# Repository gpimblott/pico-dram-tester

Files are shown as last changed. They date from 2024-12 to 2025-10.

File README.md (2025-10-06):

# Pico DRAM Tester

Having trouble with your old-school DIP dynamic RAM chips? Here's a simple
RAM tester that will give you a definitive pass or fail for a variety of
chips.

**This is an updated version with additional tests and refaftoring of the code.
Based on the early beta release by schlae . The software is not completed. Feel free to
build a tester and try it out, and submit bug reports.**

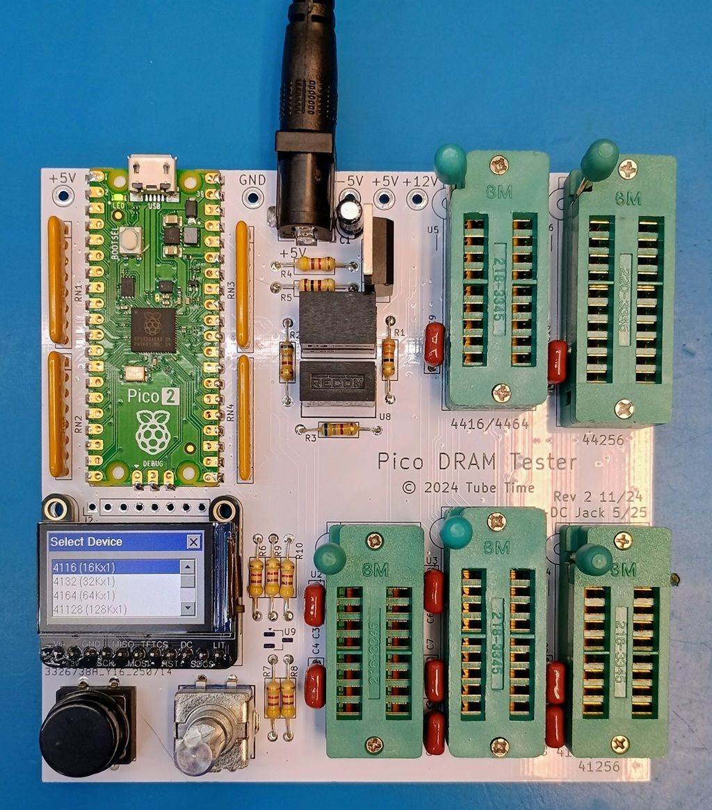
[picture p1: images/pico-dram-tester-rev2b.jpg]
Photo of the board


Benefits

* Tests RAM *at full speed* so you can feel confident about a chip that passes.
* Easy to construct with widely-available parts. No surface mount chips.
* Low cost
* Built-in DC-DC modules generate extra voltages required by 4116-class chips
* Can be operated from a bench supply for voltage margin testing

Supported Devices

* 4027 (4K x 1)
* 4108 (8K x 1 that are 4116s with only half test good: MK4108, TMS4108, etc)
* 4116 (16K x 1)
* 4132 (32K x 1, piggyback)
* 4132 (32K x 1 that are 4164s with only half tested good: TMS4532, M3732)
* 4164 (64K x 1)
* 41128 (128K x 1, piggyback)
* 41256 (256K x 1)
* 4416 (16K x 4)
* 4464 (64K x 4)
* 44256 (256K x 4)

Out of scope

* SRAM, DRAM chips larger than 1MBit
* Logic chips

## Versions
* 0.1 - Beta version designed and coded by schlae (@tubetime)
* 0.2 - Changed to higher voltage as recommended by schlae in notes below.
* 0.3 - Restructure code by G.Pimblott and merged in board changes for DC Jack by Markeno76
* 0.4 - Added Checkerboard test
* 0.5 - Added Address error test

## Construction

Revision 2.2 adds a DC Barrel Jack option.  
It also adds solder jumper pads to allow use of the original Panasonic Encoder
or the common Generic Encoders.

[Fab package](fab/pico-dram-tester-rev2.zip)

[Schematic](pico-dram-tester.pdf)

[Bill of Materials](pico-dram-tester.csv)

The board is a simple 2-layer board, 100mm x 100mm, and 1.6mm thick. Fabricate
at your favorite vendor in any color you wish.

You may populate the board only with the sockets for devices you plan to use,
or you may populate all the sockets. You can try substituting the sockets with
standard IC sockets, but I recommend ZIF sockets which are much easier to use.
Why so many sockets? It saves you from having to install dozens of pin control
transistors required to make a tester work with a single universal socket.

Populate Q1, U7, U8, R2, R3, R4, and R5 if you would like to test 4116 and
4132 devices without requiring an external -5V and +12V power supply.

If you want to provide the -5V, +5V, and +12V power from your bench supply,
then you may leave those components off of the board and connect your power
leads to the -5V, +5V, and +12V test points. If you don't plan to test 4116
or 4132 chips, then you can safely leave out those components.

The LCD display is nominally the [Adafruit 4383](https://www.adafruit.com/product/4383) which is to be installed at location J1 (U9 is not required when using
this display). You can also use cheaper devices available from Aliexpress and
others. They are 8-pin LCD displays sold as 1.14" 135x240 IPS ST7789 modules.
Install this display at position J2. You may also need to add the voltage
monitor at position U9.

For several reasons, this board requires a Pico 2 microcontroller board and
will not work at all with the Pico 1.

After installing all the components and inspecting the board for accidental
short circuits, connect the Pico 2 via the USB connector to a computer. The
device should power up and appear as a USB mass storage device. Copy the
prebuilt firmware file [pmemtest.uf2](firmware/pmemtest.uf2) to this device, and the Pico 2 will
program itself. Reset the power and you should see a menu of chips on the LCD
screen.

## Using the DRAM Tester

Before starting, connect the tester to a power source:

* If you did not install U7 and U8, connect a bench supply to the GND, -5V, +5V, and +12V test points. Connect the Pico 2 USB jack to a power adapter or computer.
* If you installed U7 and U8, connect a 5V bench supply to the 5VIN and GND test points. Instead of a bench supply, you could connect the Pico 2 USB jack to a power adapter, but you won't be able to control the voltage. A computer often has a much lower voltage and you may fail RAM chips that actually function at 5V.

1. Install the chip in the socket designated for that type of memory chip, following the pin 1 orientation (the pin 1 notch faces the ZIF socket lever). Note that some of the sockets are used for several types of memory.
2. Rotate the selection knob until the correct part number is highlighted, and push down on the top of the selection knob (it's also a button!)
3. If you make a mistake, press the button to the left of the selection knob to go back.
4. After selecting a part, you need to pick the correct speed grade to run the
test. Often the speed grade is marked on the chip as a suffix. For example, -15
typically means 150ns. If you're not sure, pick the slowest speed.
5. If you are using an external bench power supply to supply -5V and +12V, turn it on now. If you soldered in the on-board voltage converter modules, you don't need to do anything. Push the top of the selection knob to continue.
6. The test runs. You will see a red "X" if the test fails or a green checkmark if the test passes.
7. You can rerun the test immediately by pushing down on the top of the selection knob. Or go back to the menu by pushing the button to the left.

Note: The visualization pane on the left is just for entertainment and doesn't
really represent bad bits.

## Technical Details

The Pico 2 microcontroller (RP2350) has built-in high-speed PIO processors
which are overclocked to 300MHz. This means that the DRAM timing can be set
to a resolution of 3.3ns. The RAM test runs on the second CPU core, decoupling
it from the GUI, which runs on the first CPU core.

RAM testing can be surprisingly complicated. There are many kinds of failures:

* Stuck-at fault - a cell is stuck at a 1 or a 0
* Stuck-open fault - a cell isn't connected (input or output)
* Transition fault - a cell can't go from one state to another (1 to 0 or 0 to 1)
* Data retention fault - a cell flips after a time delay
* Coupling fault - the state of one cell affects the state of another
* Neighborhood pattern sensitive fault - a specific pattern in nearby cells causes a cell to flip
* Address decoder fault - cells may be isolated, or multiple cells accessed at the same address, or multiple addresses may access a single cell

There are a number of "traditional" RAM tests such as the checkerboard or
walking 1/0, but these tests can be slow and don't have precise coverage over
all failure modes. The Pico DRAM Tester uses more modern testing algorithms:

* March-B. This is a sequence of linear reads and writes designed to catch address faults, stuck-at faults, transition faults, and coupling faults.
* Pseudorandom test. This test loads a pseudorandom number sequence into the memory, reads it back, and checks to make sure it didn't change. The test is repeated with 64 different pseudorandom patterns to enhance coverage. The patterns are identical between runs, making the test repeatable. The test only uses pseudorandom data and does not randomize the address. This test can detect many pattern-sensitive faults.
* Refresh test. This test loads a pattern into the memory, waits for a time delay, and then tries to read it back. The time delay is longer than a typical refresh rate. This test can detect data retention faults.

## Known Issues

* The 41128 test is not yet reliable.

## Troubleshooting

Check your solder connections. Does the Pico 2 board show up in bootloader mode when you plug it into a computer?

The Pico DRAM Tester uses an overclocked Pico 2 configuration.
Some Pico 2 boards may not work well at 300MHz, crashing or not drawing the GUI on the screen correctly.
You may be able to get it working by editing pmemtest.c, find the line `vreg_set_voltage(VREG_VOLTAGE_1_15);` and change the voltage setting to `VREG_VOLTAGE_1_20`.

## License

This work is licensed under a Creative Commons Attribution-ShareAlike 4.0
International License. See [https://creativecommons.org/licenses/by-sa/4.0/](https://creativecommons.org/licenses/by-sa/4.0/).

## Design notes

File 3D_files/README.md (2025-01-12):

# Rotary encoder knob

For those who want one, rotary_encoder_8mm.stl is a STL file of a knob for the rotary encoder made with the help of this script:

 Trimmer/Potentiometer/Rotary encoder knob (customizable) by wanderlustig on Thingiverse: https://www.thingiverse.com/thing:6752822

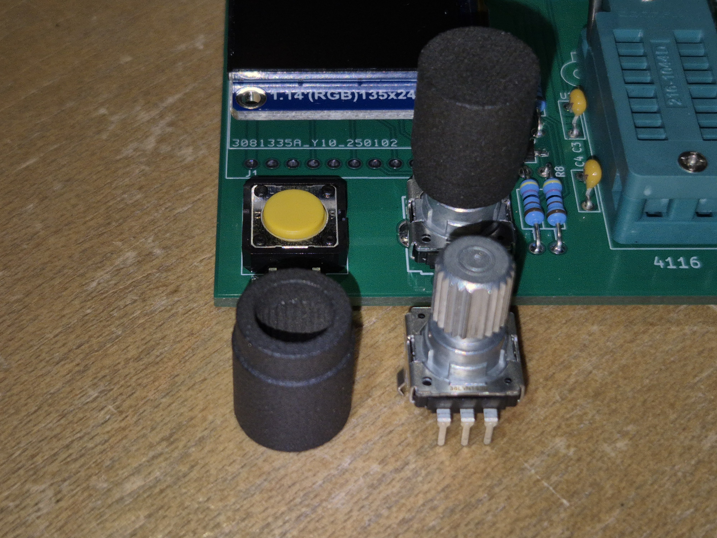
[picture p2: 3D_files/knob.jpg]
Photo of the printed knob


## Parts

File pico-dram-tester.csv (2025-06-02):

Qty | Reference | Value | DNP | Mouser
1 | C1 | 10uF |  | 667-ECA-1VM100
9 | C2,C3,C4,C5,C6,C7,C8,C9,C10 | 0.1uF |  | 80-C322C104M5U
1 | J1 | TFT 4383
1 | J2 | mrd_114_ips_lcd_8p
1 | Q1 | SUP53P06-20-E3 or equiv |  | 781-SUP53P06-20-E3
1 | R1 | 33 |  | 594-MBB02070C3309FCT
2 | R2,R3 | 680 |  | 594-MBB02070C6800FCT
6 | R4,R6,R7,R8,R9,R10 | 4.7K |  | 594-MBB02070C4701FCT
1 | R5 | 100 |  | 594-MBB02070C1000FCT
4 | RN1,RN2,RN3,RN4 | 33 |  | 652-4608X-2LF-33
1 | SW1 | RotaryEncoder_Switch |  | 667-EVE-YBCAJO16B
1 | SW2 | BACK |  | 653-B3F-4005
1 | TP1 | 5V |  | 534-5005
2 | TP2,TP6 | GND |  | 534-5006
1 | TP3 | 12V |  | 534-5009
1 | TP4 | -5V |  | 534-5007
1 | TP5 | 5VIN |  | 534-5005
1 | U1 | PICO2 |  | 358-SC1631
1 | U2 | 4116
1 | U3 | 4132
1 | U4 | 4164/41128/41256
1 | U5 | 4416/4464
1 | U6 | 44256
1 | U7 | DCDC_ITR03 |  | 490-ITR0305S12
1 | U8 | RFM-0505S |  | 919-RFM-0505S
1 | U9 | APX803S |  | 621-APX803S-29SA-7

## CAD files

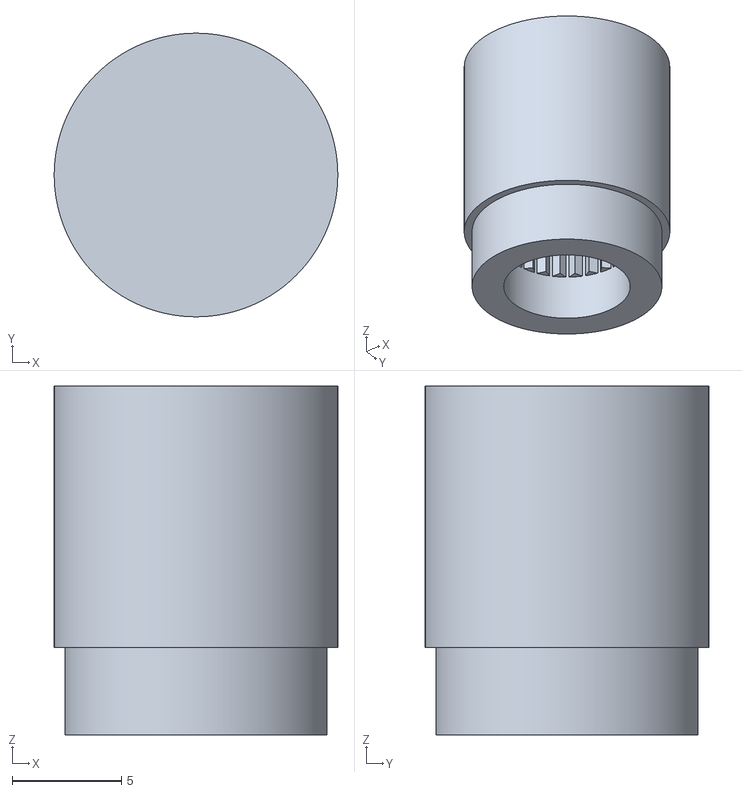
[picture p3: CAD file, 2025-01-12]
3D_files/rotary_encoder_8mm.stl
13.0 x 13.0 x 16.0

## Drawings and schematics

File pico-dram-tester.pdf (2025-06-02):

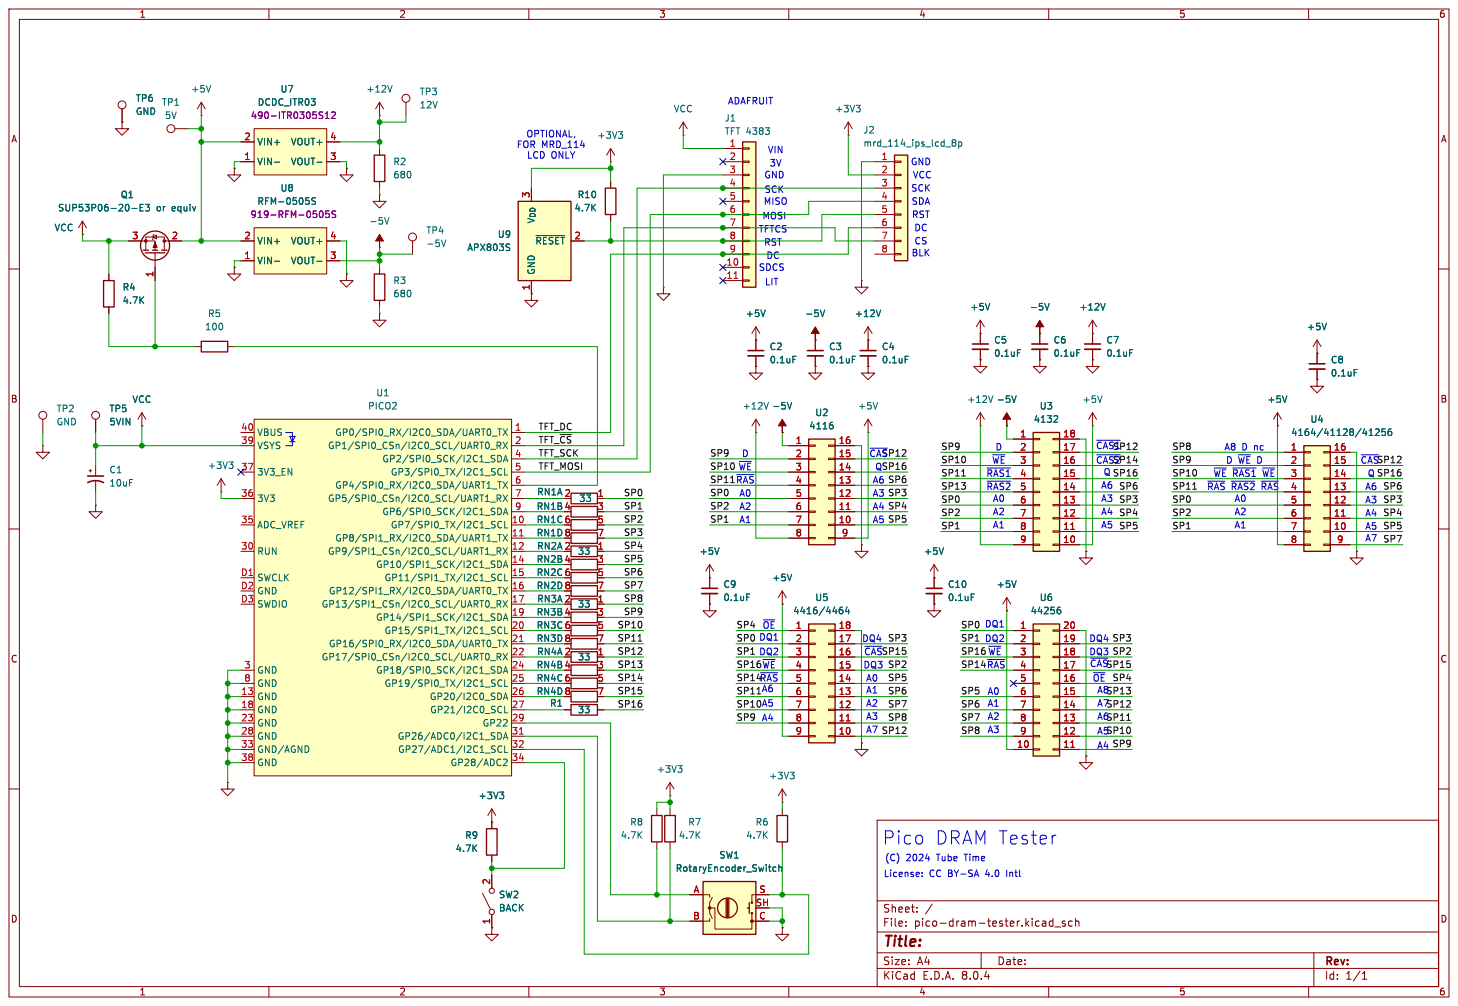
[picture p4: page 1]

License: CC BY-SA 4.0 Intl (C) 2024 Tube Time Pico DRAM Tester

Id: 1/1 Title: File: pico-dram-tester.kicad_sch Sheet: /

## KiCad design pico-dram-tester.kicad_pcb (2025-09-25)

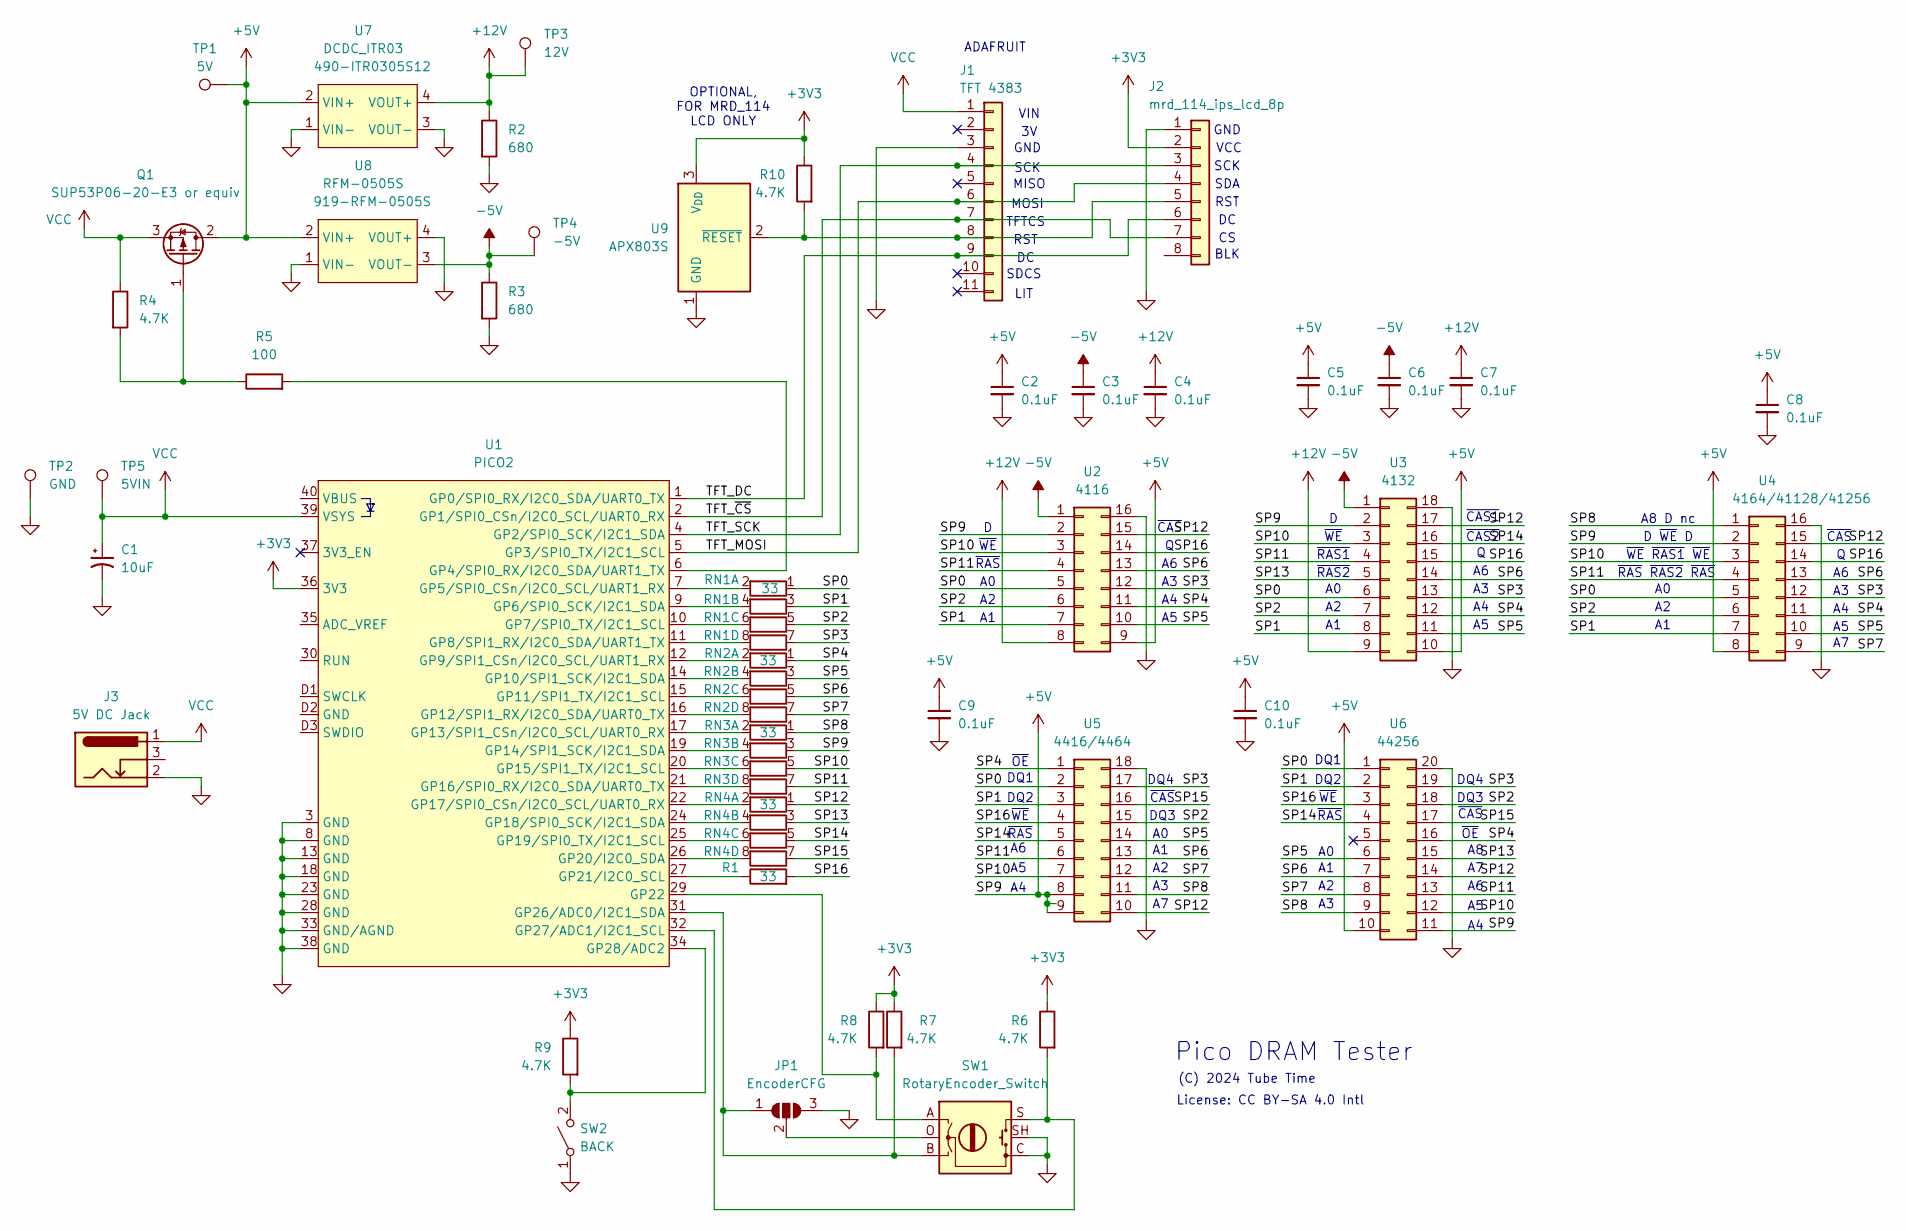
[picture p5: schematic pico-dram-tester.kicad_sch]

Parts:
C1: 10uF; CAPAE200P500X1100; Mouser 667-ECA-1VM100
C2, C3, C4, C5, C6, C7, C8, C9, C10: 0.1uF; CAPAC200; Mouser 80-C322C104M5U
J1: TFT 4383; ADAFRUIT_4383
J2: mrd_114_ips_lcd_8p; PinHeader_1x08_P2.54mm_Vertical
J3: 5V DC Jack; BarrelJack_Horizontal
JP1: EncoderCFG; SolderJumper-3_P1.3mm_Open_Pad1.0x1.5mm
Q1: SUP53P06-20-E3 or equiv; TO-220-3_Vertical; Mouser 781-SUP53P06-20-E3
R1: 33; RESA500; Mouser 594-MBB02070C3309FCT
R2, R3: 680; RESA500; Mouser 594-MBB02070C6800FCT
R4, R6, R7, R8, R9, R10: 4.7K; RESA500; Mouser 594-MBB02070C4701FCT
R5: 100; RESA500; Mouser 594-MBB02070C1000FCT
RN1, RN2, RN3, RN4: 33; R_Array_SIP8; Mouser 652-4608X-2LF-33
SW1: RotaryEncoder_Switch; PANASONIC_EVEY; Mouser 667-EVE-YBCAJO16B
SW2: BACK; SW_SPST_Omron_B3F-50xx; Mouser 653-B3F-4005
TP1: 5V; TestPoint_Keystone_5005-5009_Compact; Mouser 534-5005
TP2: GND; TestPoint_Keystone_5005-5009_Compact; Mouser 534-5006
TP3: 12V; TestPoint_Keystone_5005-5009_Compact; Mouser 534-5009
TP4: -5V; TestPoint_Keystone_5005-5009_Compact; Mouser 534-5007
TP5: 5VIN; TestPoint_Keystone_5005-5009_Compact; Mouser 534-5005
U1: PICO2; Pico2; Mouser 358-SC1631
U2: 4116; DIP_Socket-16_W4.3_W5.08_W7.62_W10.16_W10.9_3M_216-3340-00-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
U3: 4132; DIP_Socket-18_W4.3_W5.08_W7.62_W10.16_W10.9_3M_218-3341-00-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
U4: 4164/41128/41256; DIP_Socket-16_W4.3_W5.08_W7.62_W10.16_W10.9_3M_216-3340-00-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
U5: 4416/4464; DIP_Socket-18_W4.3_W5.08_W7.62_W10.16_W10.9_3M_218-3341-00-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
U6: 44256; DIP_Socket-20_W4.3_W5.08_W7.62_W10.16_W10.9_3M_220-3342-00-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
U7: DCDC_ITR03; Mouser 490-ITR0305S12
U8: RFM-0505S; DCDC_ITR03; Mouser 919-RFM-0505S
U9: APX803S; SOT-23_Handsoldering; Mouser 621-APX803S-29SA-7

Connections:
+3V3: J2.2, R6.1, R7.1, R8.1, R9.1, R10.1, U1.36 (3V3), U9.3 (V_{DD})
+5V: C2.1, C5.1, C8.1, C9.1, C10.1, Q1.2 (D), RN3.3 (R2.1), TP1.1, U2.2, U2.9, U3.2, U3.10, U4.2, U4.8, U5.8, U5.9, U6.10, U6.11, U7.2 (VIN+), U8.2 (VIN+)
+12V: C4.1, C7.1, R2.1, TP3.1, U2.8, U3.9, U7.4 (VOUT+)
-5V: C3.1, C6.1, R3.1, TP4.1, U2.1, U3.1, U8.3 (VOUT-)
/SP0: RN1.1 (R1.1), U2.5, U3.6, U4.5, U5.2, U6.1
/SP1: RN1.3 (R2.1), U2.7, U3.8, U4.7, U5.3, U6.2
/SP2: RN1.5 (R3.1), U2.6, U3.7, U4.6, U5.15, U6.18
/SP3: RN1.7 (R4.1), U2.12, U3.13, U4.12, U5.17, U6.19
/SP4: RN2.1 (R1.1), U2.11, U3.12, U4.11, U5.1, U6.16
/SP5: RN2.3 (R2.1), U2.10, U3.11, U4.10, U5.14, U6.6
/SP6: RN2.5 (R3.1), U2.13, U3.14, U4.13, U5.13, U6.7
/SP7: RN2.7 (R4.1), U4.9, U5.12, U6.8
/SP8: RN3.1 (R1.1), U4.1, U5.11, U6.9
/SP10: RN3.5 (R3.1), U2.3, U3.3, U4.3, U5.7, U6.12
/SP11: RN3.7 (R4.1), U2.4, U3.4, U4.4, U5.6, U6.13
/SP12: RN4.1 (R1.1), U2.15, U3.17, U4.15, U5.10, U6.14
/SP13: RN4.3 (R2.1), U3.5, U6.15
/SP14: RN4.5 (R3.1), U3.16, U5.5, U6.4
/SP15: RN4.7 (R4.1), U5.16, U6.17
/SP16: R1.2, U2.14, U3.15, U4.14, U5.4, U6.3
/TFT_DC: J1.9, J2.6, U1.1 (GP0/SPI0_RX/I2C0_SDA/UART0_TX)
/TFT_MOSI: J1.6, J2.4, U1.5 (GP3/SPI0_TX/I2C1_SCL)
/TFT_SCK: J1.4, J2.3, U1.4 (GP2/SPI0_SCK/I2C1_SDA)
/TFT_~CS: J1.7, J2.7, U1.2 (GP1/SPI0_CSn/I2C0_SCL/UART0_RX)
GND: C1.2, C2.2, C3.2, C4.2, C5.2, C6.2, C7.2, C8.2, C9.2, C10.2, J1.3, J2.1, J3.2, JP1.3 (B), R2.2, R3.2, SW1.C, SW1.SH, SW2.1 (A), TP2.1, U1.3 (GND), U1.8 (GND), U1.13 (GND), U1.18 (GND), U1.23 (GND), U1.28 (GND), U1.33 (GND/AGND), U1.38 (GND), U2.16, U3.18, U4.16, U5.18, U6.20, U7.1 (VIN-), U7.3 (VOUT-), U8.1 (VIN-), U8.4 (VOUT+), U9.1 (GND)
unnamed: J1.8, J2.5, R10.2, U9.2 (~RESET)
unnamed: JP1.1 (A), R7.2, SW1.B, U1.31 (GP26/ADC0/I2C1_SDA)
unnamed: JP1.2 (C), SW1.O
unnamed: Q1.1 (G), R4.2, R5.1
unnamed: RN1.2 (R1.2), U1.7 (GP5/SPI0_CSn/I2C0_SCL/UART1_RX)
unnamed: RN1.4 (R2.2), U1.9 (GP6/SPI0_SCK/I2C1_SDA)
unnamed: RN1.6 (R3.2), U1.10 (GP7/SPI0_TX/I2C1_SCL)
unnamed: RN1.8 (R4.2), U1.11 (GP8/SPI1_RX/I2C0_SDA/UART1_TX)
unnamed: RN2.2 (R1.2), U1.12 (GP9/SPI1_CSn/I2C0_SCL/UART1_RX)
unnamed: RN2.4 (R2.2), U1.14 (GP10/SPI1_SCK/I2C1_SDA)
unnamed: RN2.6 (R3.2), U1.15 (GP11/SPI1_TX/I2C1_SCL)
unnamed: RN2.8 (R4.2), U1.16 (GP12/SPI1_RX/I2C0_SDA/UART0_TX)
unnamed: RN3.2 (R1.2), U1.17 (GP13/SPI1_CSn/I2C0_SCL/UART0_RX)
unnamed: RN3.4 (R2.2), U1.19 (GP14/SPI1_SCK/I2C1_SDA)
unnamed: RN3.6 (R3.2), U1.20 (GP15/SPI1_TX/I2C1_SCL)
unnamed: RN3.8 (R4.2), U1.21 (GP16/SPI0_RX/I2C0_SDA/UART0_TX)
unnamed: RN4.2 (R1.2), U1.22 (GP17/SPI0_CSn/I2C0_SCL/UART0_RX)
unnamed: RN4.4 (R2.2), U1.24 (GP18/SPI0_SCK/I2C1_SDA)
unnamed: RN4.6 (R3.2), U1.25 (GP19/SPI0_TX/I2C1_SCL)
unnamed: RN4.8 (R4.2), U1.26 (GP20/I2C0_SDA)
unnamed: R9.2, SW2.2 (B), U1.34 (GP28/ADC2)
unnamed: R5.2, U1.6 (GP4/SPI0_RX/I2C0_SDA/UART1_TX)
unnamed: R1.1, U1.27 (GP21/I2C0_SCL)
unnamed: R8.2, SW1.A, U1.29 (GP22)
unnamed: R6.2, SW1.S, U1.32 (GP27/ADC1/I2C1_SCL)
VCC: C1.1, J1.1, J3.1, Q1.3 (S), R4.1, TP5.1, U1.39 (VSYS)

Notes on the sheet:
~{OE}
~{CAS}
~{RAS}
ADAFRUIT
GND
BLK
LIT
~{WE}
~{CAS2}
~{CAS1}
License: CC BY-SA 4.0 Intl
MOSI
DQ2
SDCS
(C) 2024 Tube Time
DQ3
~{RAS} ~{RAS2} ~{RAS}
OPTIONAL, FOR MRD_114 LCD ONLY
A8 D nc
DQ1
TFTCS
DQ4
SCK
~{RAS1}
~{RAS2}
VIN
SDA
VCC
Pico DRAM Tester
D ~{WE} D
~{WE} ~{RAS1} ~{WE}
RST
MISO

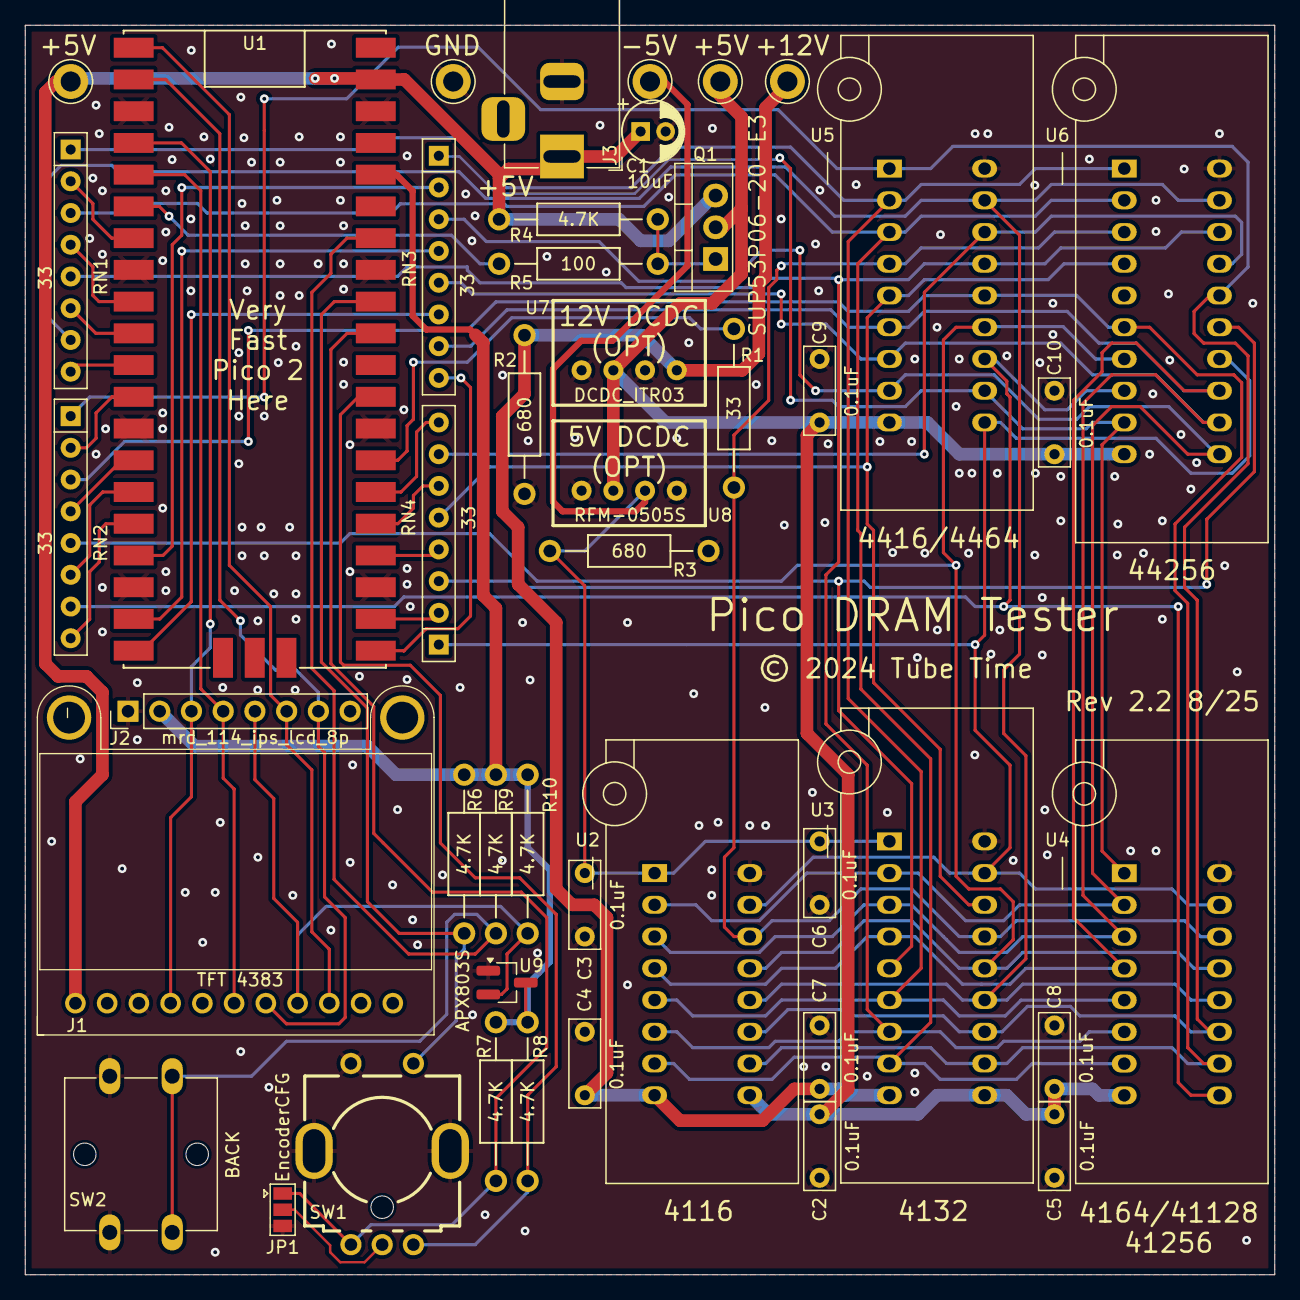
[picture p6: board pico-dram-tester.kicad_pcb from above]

Board: 2 copper layers, 100.0 x 100.0 mm, 45 parts (0 on the bottom side), 51 nets.

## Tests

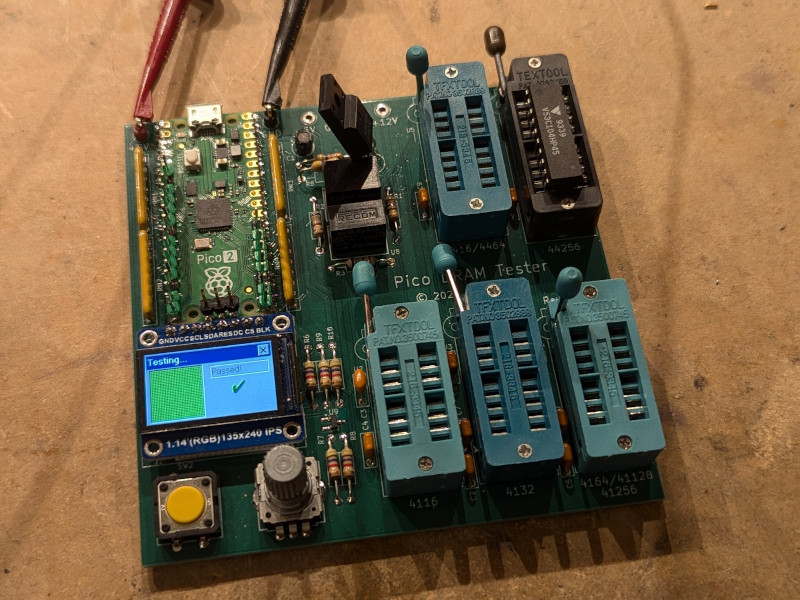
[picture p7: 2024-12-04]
pico-dram-tester.jpg

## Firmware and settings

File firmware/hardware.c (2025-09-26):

/*
 * hardware.c
 *
 * This file provides functions for controlling hardware components
 * such as power to the DRAM chip and handling input from buttons
 * and a rotary encoder.
 */

#include "hardware.h"
#include "app_state.h"
#include "pico/stdlib.h"

/**
 * @brief Turns on power to the DRAM chip.
 *
 * Configures the GPIO pin connected to the power control as an output
 * and sets it to a low state (active-low power control).
 * Includes a small delay for power stabilization.
 */
void power_on()
{
    gpio_set_dir(GPIO_POWER, true);  // Set power control pin as output
    gpio_put(GPIO_POWER, false);     // Set pin low to turn on power
    sleep_ms(100);                   // Wait for power to stabilize
}

/**
 * @brief Turns off power to the DRAM chip.
 *
 * Configures the GPIO pin connected to the power control as an input
 * (effectively high-impedance) to turn off power.
 */
void power_off()
{
    gpio_set_dir(GPIO_POWER, false); // Set power control pin as input (power off)
}

/**
 * @brief Initializes GPIO pins for the rotary encoder and buttons.
 *
 * Sets up the quadrature encoder pins (A and B), the encoder's push button,
 * and the dedicated back button as inputs.
 */
void init_buttons_encoder()
{
    // Initialize GPIO pins
    gpio_init(GPIO_QUAD_A);
    gpio_init(GPIO_QUAD_B);
    gpio_init(GPIO_QUAD_BTN);
    gpio_init(GPIO_BACK_BTN);
    // Set GPIO pins as inputs
    gpio_set_dir(GPIO_QUAD_A, GPIO_IN);
    gpio_set_dir(GPIO_QUAD_B, GPIO_IN);
    gpio_set_dir(GPIO_QUAD_BTN, GPIO_IN);
    gpio_set_dir(GPIO_BACK_BTN, GPIO_IN);

}

// Debounce count for rotary encoder pins (shorter debounce)
#define ENC_DEBOUNCE_COUNT 1000
// Debounce count for push buttons (longer debounce)
#define BUTTON_DEBOUNCE_COUNT 50000

/**
 * @brief Performs debouncing for a given GPIO pin.
 *
 * Increments a counter if the pin is high, resets it if low. Returns 1 if
 * the pin has been high for `ENC_DEBOUNCE_COUNT` consecutive checks, 0 otherwise.
 *
 * @param d Pointer to a `pin_debounce_t` structure holding pin and counter state.
 * @return 1 if the pin is considered stable high, 0 otherwise.
 */
uint8_t do_debounce(pin_debounce_t *d)
{
    if (gpio_get(d->pin)) { // If pin is currently high
        d->hcount++;
        // Prevent overflow, cap at debounce count
        if (d->hcount > ENC_DEBOUNCE_COUNT) d->hcount = ENC_DEBOUNCE_COUNT;
    } else { // If pin is currently low
        d->hcount = 0; // Reset counter
    }
    // Return true if high count reaches debounce threshold
    return (d->hcount >= ENC_DEBOUNCE_COUNT) ? 1 : 0;
}

/**
 * @brief Checks if a button has been pushed, returning true only once per press.
 *
 * This function implements a stateful debouncing mechanism for buttons.
 * It returns true when a button is first detected as pressed after being released,
 * and then remains false until the button is released and pressed again.
 *
 * @param pin_b Pointer to a `pin_debounce_t` structure for the button.
 * @return True if the button was just pushed, false otherwise.
 */
bool is_button_pushed(pin_debounce_t *pin_b)
{
    if (!gpio_get(pin_b->pin)) { // If button is currently pressed (assuming active-low)
        if (pin_b->hcount == 0) { // If this is the first detection of a press
            pin_b->hcount = BUTTON_DEBOUNCE_COUNT; // Set counter to debounce threshold
            return true; // Indicate button was pushed
        }
    } else { // If button is currently released
        if (pin_b->hcount > 0) {
            pin_b->hcount--; // Decrement counter, allowing for next press detection
        }
    }
    return false; // Button not pushed or still debouncing
}

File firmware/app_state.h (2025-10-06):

#ifndef APP_STATE_H
#define APP_STATE_H

#include <stdint.h>
#include "pico/stdlib.h"
#include "pico/util/queue.h"
#include "hardware/pio.h"
#include "gui.h"
#include "mem_chip.h"

#define APP_VERSION "Version 0.5"

#define GPIO_POWER 4
#define GPIO_QUAD_A 22
#define GPIO_QUAD_B 26
#define GPIO_QUAD_BTN 27
#define GPIO_BACK_BTN 28
#define GPIO_LED 25

// NUmber of sizes of memory chips supported
#define MAIN_MENU_ITEMS 16
#define NUM_CHIPS 12
#define PSEUDO_VALUES 64

// Change the Rotary Encoder sensitivity here (1=high, 2=medium, 4=low)
#define ENCODER_SENSITIVITY 2

// Enums
typedef enum {
    SPLASH_SCREEN,
    MAIN_MENU,
    VARIANT_MENU,
    SPEED_MENU,
    DO_SOCKET,
    DO_TEST,
    TEST_RESULTS
} gui_state_t;

// Extern declarations for global variables

// PIO
extern PIO pio;
extern uint sm;
extern uint offset;

// Test Status
extern volatile int stat_cur_addr;
extern volatile int stat_old_addr;
extern volatile int stat_cur_bit;
extern queue_t stat_cur_test;
extern volatile int stat_cur_subtest;
extern uint ram_bit_mask;

// GUI
extern gui_listbox_t *cur_menu;
extern char *main_menu_items[MAIN_MENU_ITEMS];
extern gui_listbox_t main_menu;
extern gui_listbox_t variants_menu;
extern gui_listbox_t speed_menu;
extern gui_state_t gui_state;
extern struct repeating_timer drum_timer;

// Chip Data
extern const mem_chip_t *chip_list[NUM_CHIPS];
extern const char *ram_test_names[];

// Multicore
extern queue_t call_queue;
extern queue_t results_queue;

// Pseudorandom Test
extern uint64_t random_seeds[PSEUDO_VALUES];

#endif //APP_STATE_H

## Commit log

2024-10-12 tweaks to st7789 driver
2024-10-22 first PCB fab
    [pico-dram-tester.kicad_pcb, pico-dram-tester.kicad_sch]
2024-10-25 button and quadrature encoder
2024-10-29 Fix PIO allocation leak
    [pmemtest.c]
2024-11-05 Layout corrections
    [pico-dram-tester.kicad_pcb, pico-dram-tester.kicad_sch]
2024-12-04 Add readme and new fab package
    [pico-dram-tester.csv, pico-dram-tester.kicad_pcb, pico-dram-tester.kicad_sch]
2025-01-11 Added 3D_files, updated BOM
    [pico-dram-tester.csv, rotary_encoder_8mm.stl]
2025-06-02 Update MOSFET Q1, fix R1 part number
    [pico-dram-tester.csv, pico-dram-tester.kicad_sch]
2025-08-02 DCJack and Generic Encoder
    Added DC Barrel Jack. Added Configuration Jumper pads to use the common Generic Encoder
    [pico-dram-tester.kicad_pcb, pico-dram-tester.kicad_sch]
2025-08-03 Fix: ps and refresh tests no longer write all '1'
    [pmemtest.c]
2025-08-05 Fix back button bug
    [pmemtest.c]
2025-08-07 Add 4027. Fix missing menu items.
    [pmemtest.c]
2025-08-07 Add RAS initialization after powerup
2025-08-27 Add 4408 support. Fix debounce.
    [pmemtest.c]
2025-09-24 Increase the voltage to work with my board
2025-09-26 Create c-cpp.yml
    Pico build action
2025-09-26 set the voltage to 1.25v
2025-09-28 Reset voltage to see if it helps stability
    [pmemtest.c]
2025-09-28 Ensure that the cores are reset after an SWD flash - might not help
    [pmemtest.c]
2025-09-28 Rotary encoder sensitivty

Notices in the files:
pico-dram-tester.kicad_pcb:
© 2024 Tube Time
